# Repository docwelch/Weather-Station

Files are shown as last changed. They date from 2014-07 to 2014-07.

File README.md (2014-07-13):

Weather-Station
===============

This is a weather station created with components from Sparkfun. The Arduino firmware is a modified version of Sparkfun's Wimp Weather Station. While the Imp is an interesting device, I wanted to get the weather data back to a BeagleBone Black for further processing/evaluation. The BeagleBone Black can easily push the data to Weather Underground. 

##Equipment

To set up your station, please follow the [Sparkfun tutorial](https://learn.sparkfun.com/tutorials/weather-station-wirelessly-connected-to-wunderground). Obviously, you won't need the Imp or the Imp shield. In its place, you will need an XBee shield, an XBee breakout (with headers) and and two XBees. I am using XBee Pro modules due to the distance and other factors. You will need *three* sets of Arduino headers (one for the XBee shield and two for the weather shield) because the weather shield is so tall. So that we can turn the XBee off and on to conserve power, you will need a connection between the XBee pin 9 and digital pin 4 on the RedBoard.

I am using a BeagleBone Black Rev. C (a Rev. B board would work as well if you have one) running [Debian](http://beagleboard.org/latest-images/). You will need to have your BeagleBone Black connected to the internet (wired or wireless) if you want to push your data to Weather Underground. On the P9 header of the BeagleBone Black, connect pin 1 to ground on the XBee breakout, pin 3 to VCC on the XBee breakout, pin 21 (Serial 2 TX) to DIN on the XBee breakout, and pin 26 (Serial 1 RX) to DOUT on the XBee breakout.

To house the electronics, I 3-d printed a Stevenson Screen. I used the pins.scad file from [Thingiverse](http://www.thingiverse.com/thing:10541/#files) to create pins and sockets to make it easy to assemble/disassemble the screen. I have included the .STL files for printing and the OpenScad file for the bottom so that you may modify it for your own mounting system. The Stevenson screen is printed in white PLA. It remains to be seen how durable the PLA will be. You build the assembly with a top, a middle, a middle grid, two more middles, and a bottom. The battery and Sunny Buddy sit on top of the middle grid. The bottom has holes to mount the RedBoard and the two shields.
For now, I have the solar panel mounted in a manner similar to the Sparkfun Wimp Weather Station. I am thinking of designing a gimbal driven by two servos to track the sun. There should still be enough memory on the RedBoard for this.

##Libraries

You will need the [xbee-arduino library](https://code.google.com/p/xbee-arduino/) as well as the [pressure](https://github.com/sparkfun/MPL3115A2_Breakoutand) and [humidity](https://github.com/sparkfun/HTU21D_Breakout) sensor libraries from Sparkfun. 
For the BeagleBone Black, you will need (in addition to libraries bonescript, socketio, and serial installed by default) [xbee-api](https://www.npmjs.org/package/xbee-api) and [moment](https://www.npmjs.org/package/moment). Unless you are using the latest Bonescript from Github, you need to modify your serial.js file (found in /usr/local/lib/node_modules/bonescript) to include the following line at the end of the file: `exports.serialParsers = m.module.exists ? m.module.parsers : {};`

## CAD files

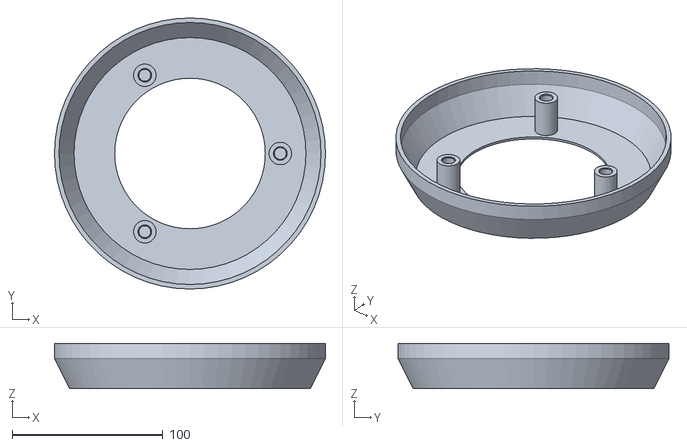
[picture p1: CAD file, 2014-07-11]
Stevenson Screen/Middle.stl
180.0 x 180.0 x 30.0

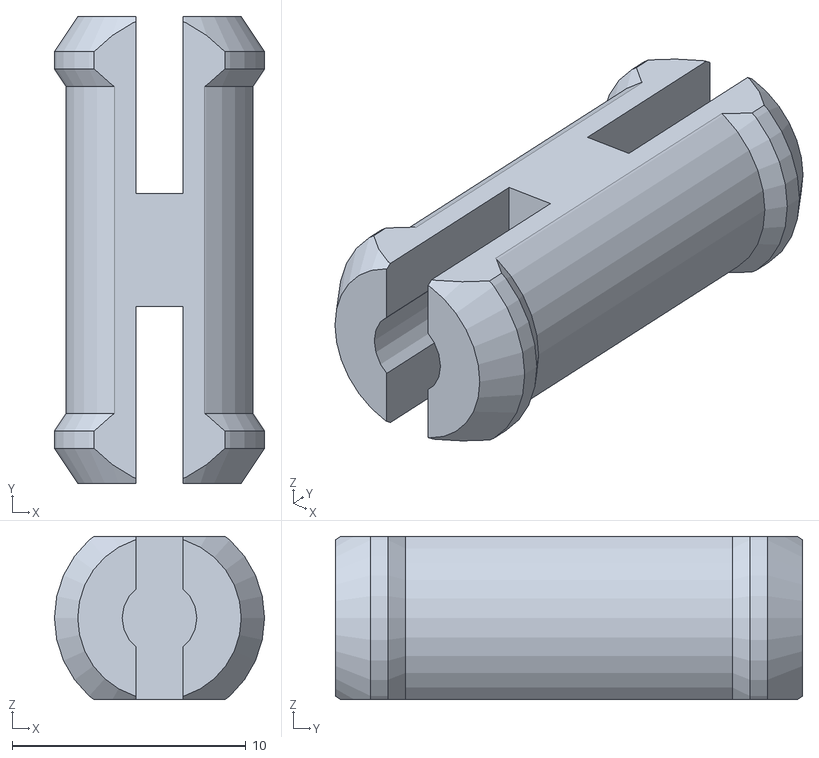
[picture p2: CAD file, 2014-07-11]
Stevenson Screen/SinglePin.stl
9.00 x 20.0 x 7.00

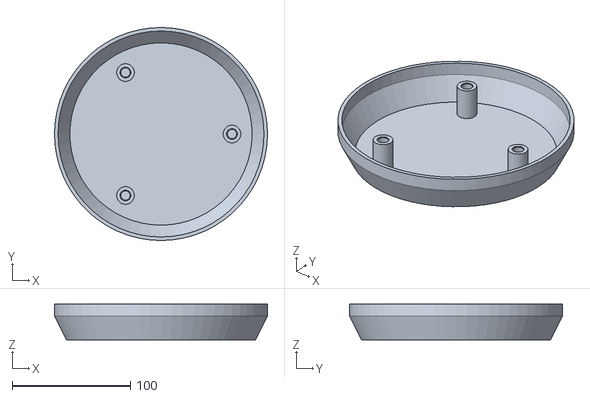
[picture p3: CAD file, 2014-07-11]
Stevenson Screen/Top.stl
180.0 x 180.0 x 30.0

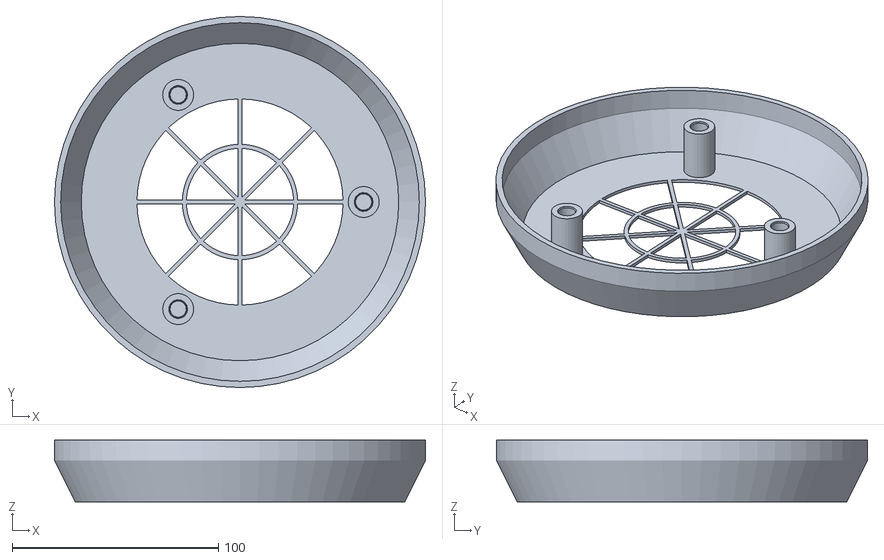
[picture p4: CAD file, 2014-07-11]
Stevenson Screen/Middle_grid.stl
180.0 x 180.0 x 30.0

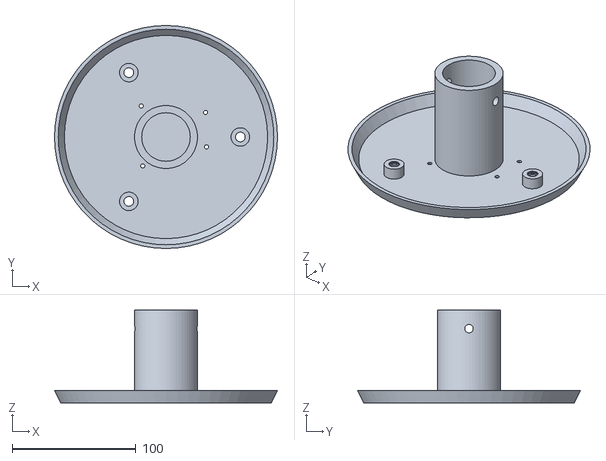
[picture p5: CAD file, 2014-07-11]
Stevenson Screen/Bottom.stl
180.0 x 180.0 x 75.0

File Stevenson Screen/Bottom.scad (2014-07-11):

include <pins.scad>;

difference(){
	union(){
		main();
		verticals();
		mount();
	}
	holes();
	rotate([180,0,0])translate([-34,-27.5,-4]){
		translate([14,2.5,0])cylinder(h=5,r=1.7,$fn=30);
		translate([66,7.62,0])cylinder(h=5,r=1.7,$fn=30);
		translate([15.25,50.8,0])cylinder(h=5,r=1.7,$fn=30);
		translate([66.7,35.50,0])cylinder(h=5,r=1.7,$fn=30);
	}
}

module mount(){
	difference(){
		cylinder(h=75, r=25.4, $fn=60);
		translate([0,0,10])cylinder(h=66, r=19.6, $fn=60);
		translate([0,0,60])rotate([0,90,0])cylinder(h=80, r=3.43, $fn=30, center=true);
	}
}

module main(){
	difference(){
		cylinder(h=10,r1=85,r2=90,$fn=60);
		translate([0,0,1.5])cylinder(h=8.6,r1=82,r2=87,$fn=60);
	}
}

module verticals(){
	translate([60,0,0])cylinder(h=10,r=7.5,$fn=30);
	rotate([0,0,120])translate([60,0,0])cylinder(h=10,r=7.5,$fn=30);
	rotate([0,0,-120])translate([60,0,0])cylinder(h=10,r=7.5,$fn=30);
}

module holes(){
	translate([60,0,0])pinhole(h=10);
	rotate([0,0,120])translate([60,0,0])pinhole(h=10);
	rotate([0,0,-120])translate([60,0,0])pinhole(h=10);
}

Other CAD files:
Stevenson Screen/pins.scad

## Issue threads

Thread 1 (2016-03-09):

No transmission data to Wunderground / Error in Arduino Function missing

golvellius, 2016-03-09:
Hi ...

First of all i would like to thank you about your supperb work .. I have been checking your code and works ok .
I have found two possible errors i can not recover ...
1) In the code of BeagleBoneBlack . The info arrives  from the arduino , it is displayed in the console of cloud9 IDE ,   but **never execute sendDataToWunderground()**; .. I see all the info comming from the arduino , but never sends data to internet ...

2) Also there is a problem in the code of the Arduino , Line ...
**baromin = myPressure.readPressureinHg(LOCAL_ALT_METERS); **
I tried to get some libraries from internet , included the ones in SPARKFUN but no luck , the function does not exist .. I have made new routine from example in SPARKFUN .. i will check ...

Maybe i make some mistake ...

Thanks a lot ...

docwelch, 2016-03-10:
For issue #1, the problem is likely a small typo in function sendDataToWunderground(). I had a lot of trouble with my system as well. Please go back and review that you have your username and password correct and no other mistakes in the function where it creates the http request. When I was setting up my station, I had to review that section several times before I finally got all the errors out of it.

For issue 2, it looks like Sparkfun has changed the library since I downloaded it. You are correct, the function no longer exists. They have made a lot of changes to the library it looks like and this will require some re-writing of the code. It should not be too difficult if you look at the example sketches [Sparkfun MPL3115A2 Pressure Sensor Library.](https://github.com/sparkfun/SparkFun_MPL3115A2_Breakout_Arduino_Library.) You can also look at [Sparkfun Wimp Weather Station Arduino Code](https://github.com/sparkfun/Wimp_Weather_Station/blob/master/Wimp_Weather_Station.ino) as it looks like Sparkfun updated this as well. Looks like you just need to set up the barometer in the void Setup() function, and then you call for pressure with just readPressure(). It returns the value in Pa so you will have to convert if you want a different unit. You will no longer need the LOCAL_ALT_METERS variable.

Glad this is useful to someone and I hope my response is helpful. Let me know if you cannot figure it out. I think I may have to take down my weather station and add the lightning sensor. I am sure I will change over to the new library and I will update the code then. However, it may be several weeks (or months) before I get to it, unfortunately. I will leave this issue open until I have time to fix the code.

golvellius, 2016-03-10:
Hi  ...
I think i have my issue  with the code .. maybe hardware xbee issue ...

What  i see is that i get data from the xbee but maybe wrong data ..

On this function ...i modified to tell me things in the console ...

xbeeAPI.on('frame_object',function(frame){
    console.log("XBEE");
    if (frame.type==C.FRAME_TYPE.RX_PACKET_16){
        console.log("XBEEIN");
        dataArray.length=0;
        weatherArray.length=0;
        var winddir=((frame.data[0]<<8)+frame.data[1]);
etc ....

I see in the console XBEE but not XBEE1 ... never execute this function ...

Can you tell me your xbee configuration .... ?

I think that this is the problem ...

golvellius, 2016-03-10:
Hi ...

Now Working .. it's a problem with the ap mode of the xbeess ... Now working OK ...

If you want i can add the code in your source to readPressure in HG ....

Thanks a lot ...

golvellius, 2016-06-07:
Hi ..

I have been using it for 2 month , but i have problems maybe with my battery charger ..
Suddenly , battery get's empty an solar panel can not charge ...

What are you using ? Solar Panel + BAttery charger + batteries ?

Thanks a lot ... Good job with this project ...
I am modifying the code to install lighting detector .... ; )

Please can you reply to me to this email golvelliuscs@hotmail.com ..

bye

docwelch, 2016-06-08:
I used a 2.5W solar cell and the Sunny Buddy MPPT charger from Sparkfun with a 5000mAh single cell LiPo battery.I never had a problem, even with several days of limited to no sunshine. I think the 5000mAh battery is probably quite a bit bigger than you would have to use, but they are cheap from HobbyKing.
Good luck with it,Steven
 Confidentiality Statement - This electronic message transmission contains information that is confidential or privileged.  The information is intended to be for the use of the individual or entity named above. If you are not the  intended recipient, be aware that any disclosure, copying, distribution or use of the contents of this information is prohibited.  If you have received this electronic transmission in error, please notify us immediately.  Thank you.

      From: golvellius <notifications@github.com>
 To: docwelch/Weather-Station <Weather-Station@noreply.github.com>
Cc: Steven Welch <docwelch@yahoo.com>; Comment <comment@noreply.github.com>
 Sent: Tuesday, June 7, 2016 5:47 AM
 Subject: Re: [docwelch/Weather-Station] No transmission data to Wunderground / Error in Arduino Function missing (#1)

Hi ..I have been using it for 2 month , but i have problems maybe with my battery charger ..
Suddenly , battery get's empty an solar panel can not charge ... What are you using ? Solar Panel + BAttery charger + batteries ?Thanks a lot ... Good job with this project ...
I am modifying the code to install lighting detector .... ; ) Please can you reply to me to this email golvelliuscs@hotmail.com ..bye —
You are receiving this because you commented.
Reply to this email directly, view it on GitHub, or mute the thread.

Closed 2016-03-11.

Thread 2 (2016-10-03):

Pressure reading error

golvellius, 2016-10-03:
Hi ...
My system :

Arduino uno R3 ( +5 volts ) + Xbee (first version) + Weather Shield ( sparkfun ) + Weather Meters ( SParkfun)+ BBB  ...
I have a problem when retrieving the pression from the arduino ...

To get a good values i need to remove this line in  the code  :

**// myPressure.setModeActive(); // Go to active mode and start measuring!**

Also i change this value (128) to (7) in this line :

 **myPressure.setOversampleRate(7); // Set Oversample to the recommended 128**

But the error is that the values i get from the sensor is too  high 255825.00 after conversion  = example 75.72 inHg ..
Sometimes i get 0 from the arduino ...

I used this formula to get the pressure from pascals to inhg :

 **payload[23] = tdailyrainin & 0xFF;**
**// Calculo la presion en hpa para enviar a wunther**

  **float pressure = baromin / 100; //pressure is now in millibars**

  **float part1 = pressure - 0.3; //Part 1 of formula**

  **const float part2 = 8.42288 / 100000.0;**
  **float part3 = pow((pressure - 0.3), 0.190284);**
  **float part4 = LOCAL_ALT_METERS / part3; // Local_Alt_Meters esta ya en coma flotante**
  **float part5 = (1.0 + (part2 * part4));**
  **float part6 = pow(part5, (1.0/0.190284));**
  **float altimeter_setting_pressure_mb = part1 * part6; //Output is now in adjusted millibars**
  **float baroin = altimeter_setting_pressure_mb * 0.02953;**

  **unsigned int tpressure = (unsigned int)(baro**in * 100);
  **payload[24] = tpressure >> 8 & 0xFF;**
  **payload[25] = tpressure & 0xFF;**

what could be the problem ...  a faulty weathershield / arduino ?

Also , sometimes i get that i have rain , but there is no raining ... maybe daily rain =0.09 , 0,10 .. etc .. if i reset the arduino rain = 0 ... after 2 hours rain =0.3 ... etc ...

Thanks so much ...

golvellius, 2016-10-19:
HI .. I think it's a problem of the sensor installed in the weathershield ...
Now i am using external sensor from bosch BMP280 and works correctly ...

Also i have added to my code an uv sensor .. i have to check if works correctly ..

Thanks a lot ... And sorry for this issue ... ;)

Closed 2016-10-19.

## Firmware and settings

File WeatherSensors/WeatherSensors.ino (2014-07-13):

/* 
 Weather Station
 By: J. Steven Welch
 July 10, 2014
 Much of this code is based on Nathan Seidle's code which is in turn based on Mike Grusin's USB Weather Board code.
 
 This code reads all the various sensors (wind speed, direction, rain gauge, humidty, pressure, light, batt_lvl)
 and sends it, via XBee, to a BeagleBone Black. The BeagleBone black then forwards that data to Weather Underground.
*/
#include <avr/wdt.h> //We need watch dog for this program
#include <Wire.h> //I2C needed for sensors
#include "MPL3115A2.h" //Pressure sensor
#include "HTU21D.h" //Humidity sensor
#include <XBee.h>

MPL3115A2 myPressure; //Create an instance of the pressure sensor
HTU21D myHumidity; //Create an instance of the humidity sensor
XBee xbee=XBee();

//Hardware pin definitions
//-=-=-=-=-=-=-=-=-=-=-=-=-=-=-=-=-=-=-=-=-=-=-=-=-=-=-=-=
// digital I/O pins
const byte WSPEED = 3;
const byte RAIN = 2;
const byte STAT1 = 7;
const byte XBEE_SLEEP_PIN = 4;

// analog I/O pins
const byte WDIR = A0;
const byte LIGHT = A1;
const byte BATT = A2;
const byte REFERENCE_3V3 = A3;
//-=-=-=-=-=-=-=-=-=-=-=-=-=-=-=-=-=-=-=-=-=-=-=-=-=-=-=-=

//Global Variables
//-=-=-=-=-=-=-=-=-=-=-=-=-=-=-=-=-=-=-=-=-=-=-=-=-=-=-=-=
//*****************************************************************
const float LOCAL_ALT_METERS=371.0; //SET FOR YOUR LOCAL ALTITUDE *
//*****************************************************************
long lastSecond; //The millis counter to see when a second rolls by
byte seconds; //When it hits 60, increase the current minute
byte seconds_2m; //Keeps track of the "wind speed/dir avg" over last 2 minutes array of data
byte minutes; //Keeps track of where we are in various arrays of data
byte minutes_10m; //Keeps track of where we are in wind gust/dir over last 10 minutes array of data

long lastWindCheck = 0;
volatile long lastWindIRQ = 0;
volatile byte windClicks = 0;
volatile long lastRainIRQ = 0;

uint8_t payload[32]; //buffer for data to send through XBee
uint8_t respData=0; //byte to hold data sent from BeagleBone to trigger events on the Arduino
//******************************************************************************************************************************
Tx16Request tx=Tx16Request(0x1000,payload,sizeof(payload)); //XBee packet to send - SET THE FIRST VALUE TO YOUR OWN XBEE VALUE *
//******************************************************************************************************************************
Rx16Response rx16 = Rx16Response();
uint8_t reportTime=20; //how often to report the weather - can be updated from BBB
uint8_t counter=0; //counter to track seconds for the above reportTime

//We need to keep track of the following variables:
//Wind speed/dir each update (no storage)
//Wind gust/dir over the day (no storage)
//Wind speed/dir, avg over 2 minutes (store 1 per second)
//Wind gust/dir over last 10 minutes (store 1 per minute)
//Rain over the past hour (store 1 per minute)
//Total rain over date (store one per day)

byte windspdavg[120]; //120 bytes to keep track of 2 minute average
int winddiravg[120]; //120 ints to keep track of 2 minute average
float windgust_10m[10]; //10 floats to keep track of 10 minute max
int windgustdirection_10m[10]; //10 ints to keep track of 10 minute max
volatile float rainHour[60]; //60 floating numbers to keep track of 60 minutes of rain

//These are all the weather values that wunderground expects:
int winddir; // [0-360 instantaneous wind direction]
float windspeedmph; // [mph instantaneous wind speed]
float windgustmph; // [mph current wind gust, using software specific time period]
int windgustdir; // [0-360 using software specific time period]
float windspdmph_avg2m; // [mph 2 minute average wind speed mph]
int winddir_avg2m; // [0-360 2 minute average wind direction]
float windgustmph_10m; // [mph past 10 minutes wind gust mph ]
int windgustdir_10m; // [0-360 past 10 minutes wind gust direction]
float humidity; // [%]
float tempf; // [temperature F]
float rainin; // [rain inches over the past hour)] -- the accumulated rainfall in the past 60 min
volatile float dailyrainin; // [rain inches so far today in local time]
float baromin;//a calculated number
float pressure;//a raw reading
float dewptf;//a calculated number

//These are not wunderground values, they are just for us
float batt_lvl = 4.0;
float light_lvl = 2.2;

// volatiles are subject to modification by IRQs
extern volatile unsigned long timer0_millis;
//-=-=-=-=-=-=-=-=-=-=-=-=-=-=-=-=-=-=-=-=-=-=-=-=-=-=-=-=

//Interrupt routines (these are called by the hardware interrupts, not by the main code)
//-=-=-=-=-=-=-=-=-=-=-=-=-=-=-=-=-=-=-=-=-=-=-=-=-=-=-=-=
void rainIRQ()
// Count rain gauge bucket tips as they occur
// Activated by the magnet and reed switch in the rain gauge, attached to input D2
{
  if (millis() - lastRainIRQ > 10)
  {
    lastRainIRQ=millis();
    dailyrainin +=0.011;
    rainHour[minutes]+=0.011;
  }
}

void wspeedIRQ()
// Activated by the magnet in the anemometer (2 ticks per rotation), attached to input D3
{
  if (millis() - lastWindIRQ > 10) // Ignore switch-bounce glitches less than 10ms (142MPH max reading) after the reed switch closes
  {
    lastWindIRQ = millis(); //Grab the current time
    windClicks++; //There is 1.492MPH for each click per second.
  }
}

void setup()
{
  wdt_reset(); //Pet the dog
  wdt_disable(); //We don't want the watchdog during init

  Serial.begin(9600);
  
  xbee.setSerial(Serial);
  pinMode(XBEE_SLEEP_PIN,OUTPUT);
  digitalWrite(XBEE_SLEEP_PIN,HIGH); //xbee is put to sleep

  pinMode(WSPEED, INPUT_PULLUP); // input from wind meters windspeed sensor
  pinMode(RAIN, INPUT_PULLUP); // input from wind meters rain gauge sensor

  pinMode(WDIR, INPUT);
  pinMode(LIGHT, INPUT);
  pinMode(BATT, INPUT);
  pinMode(REFERENCE_3V3, INPUT);
  
  pinMode(STAT1, OUTPUT);

  midnightReset(); //Reset rain totals

  //Configure the pressure sensor
  myPressure.begin(); // Get sensor online
  myPressure.setModeBarometer(); // Measure pressure in Pascals from 20 to 110 kPa
  myPressure.setOversampleRate(128); // Set Oversample to the recommended 128
  myPressure.enableEventFlags(); // Enable all three pressure and temp event flags 
  myPressure.setModeActive(); // Go to active mode and start measuring!

  //Configure the humidity sensor
  myHumidity.begin();

  seconds = 0;
  lastSecond = millis();

  // attach external interrupt pins to IRQ functions
  attachInterrupt(0, rainIRQ, FALLING);
  attachInterrupt(1, wspeedIRQ, FALLING);

  // turn on interrupts
  interrupts();

  wdt_enable(WDTO_1S); //Unleash the beast
}

void loop()
{
  wdt_reset(); //Pet the dog

  //Keep track of which minute it is
  if(millis() - lastSecond >= 1000)
  {
    lastSecond += 1000;

    //Take a speed and direction reading every second for 2 minute average
    if(++seconds_2m > 119) seconds_2m = 0;

    //Calc the wind speed and direction every second for 120 second to get 2 minute average
    float currentSpeed = get_wind_speed();
    windspeedmph=currentSpeed;
    int currentDirection = get_wind_direction();
    windspdavg[seconds_2m] = (int)currentSpeed;
    winddiravg[seconds_2m] = currentDirection;

    //Check to see if this is a gust for the minute
    if(currentSpeed > windgust_10m[minutes_10m])
    {
      windgust_10m[minutes_10m] = currentSpeed;
      windgustdirection_10m[minutes_10m] = currentDirection;
    }

    //Check to see if this is a gust for the day
    //Resets at midnight each night
    if(currentSpeed > windgustmph)
    {
      windgustmph = currentSpeed;
      windgustdir = currentDirection;
    }

    //Blink stat LED briefly to show we are alive
    digitalWrite(STAT1, HIGH);
    delay(25);
    digitalWrite(STAT1, LOW);
    
    //Is it time to report the weather?
    if (++counter>=reportTime)
    {
      counter=0;
      reportWeather();
    }
    //If we roll over 60 seconds then update the arrays for rain and windgust
    if(++seconds > 59)
    {
      seconds = 0;
      if(++minutes > 59) minutes = 0;
      if(++minutes_10m > 9) minutes_10m = 0;

      rainHour[minutes] = 0; //Zero out this minute's rainfall amount
      windgust_10m[minutes_10m] = 0; //Zero out this minute's gust
    }
  }
//******************************************
  //See if we got something from the BeagleBoneBlack
  if(respData!=0)
  {
    if(respData == 0xFE) //Indicates that it is midnight local time
    {
      midnightReset(); //Reset a bunch of variables like rain and total rain
    }
    else if(respData == 0xFF) //Force a hardware reset
    {
      delay(2500); //This will cause the system to reset because we don't pet the dog
    }else{ //We got a reportTime number
      reportTime=respData; //Can report data every 3 to 253 seconds
      //Note that Weather Underground will not take data faster than every 2.5 seconds. 
    }
    respData=0;
  }
  delay(100); //Update every 100ms. No need to go any faster.
}

//When the BBB tells us it's midnight, reset some things
//millis() gets reset to zero here as well so there are no rollover issues
void midnightReset()
{
  //reset millis
  uint8_t oldSREG=SREG;
  cli();
  timer0_millis=(long)0;
  SREG=oldSREG;
  
  dailyrainin = 0; //Reset daily amount of rain

  windgustmph = 0; //Zero out this minute's gust
  windgustdir = 0; //Zero out the gust direction
  
  minutes = 0; //Reset minute tracker
  seconds = 0;
  lastSecond = millis(); //Reset variable used to track minutes
  lastWindCheck=millis(); //Reset variable to track instantaneous wind speed
  lastRainIRQ=millis();
  lastWindIRQ=millis();
}

//Calculates each of the variables that wunderground is expecting
void calcWeather()
{
  //Calc winddir
  winddir = get_wind_direction();

  //windspeedmph already calcuated in main loop
  //windgustmph and windgustdir are calculated throughout the day

  //Calc windspdmph_avg2m
  float temp = 0;
  for(int i = 0 ; i < 120 ; i++)
    temp += windspdavg[i];
  temp /= 120.0;
  windspdmph_avg2m = temp;

  //Calc winddir_avg2m
  temp = 0; //Can't use winddir_avg2m because it's an int
  for(int i = 0 ; i < 120 ; i++)
    temp += winddiravg[i];
  temp /= 120;
  winddir_avg2m = temp;

  //Calc windgustmph_10m
  //Calc windgustdir_10m
  //Find the largest windgust in the last 10 minutes
  windgustmph_10m = 0;
  windgustdir_10m = 0;
  //Step through the 10 minutes  
  for(int i = 0; i < 10 ; i++)
  {
    if(windgust_10m[i] > windgustmph_10m)
    {
      windgustmph_10m = windgust_10m[i];
      windgustdir_10m = windgustdirection_10m[i];
    }
  }

  //Calc humidity
  humidity = myHumidity.readHumidity();

  //Calc tempf from pressure sensor
  tempf = myPressure.readTempF();

  //Total rainfall for the day is calculated within the interrupt
  //Calculate amount of rainfall for the last 60 minutes
  rainin = 0;  
  for(int i = 0 ; i < 60 ; i++)
    rainin += rainHour[i];

  //Calc pressure
  baromin = myPressure.readPressureinHg(LOCAL_ALT_METERS);

  //Calc dewptf
  float tempC=(tempf-32)*5/9.0;
  float L=log(humidity/100.0);
  float M=17.27*tempC;
  float N=237.3+tempC;
  float B=(L+(M/N))/17.27;
  dewptf=((237.3*B)/(1.0-B))*9/5.0 +32;
  
  //Calc light level
  light_lvl = get_light_level();

  //Calc battery level
  batt_lvl = get_battery_level();
}

//Returns the voltage of the light sensor based on the 3.3V rail
//This allows us to ignore what VCC might be (an Arduino plugged into USB has VCC of 4.5 to 5.2V)
float get_light_level()
{
  float operatingVoltage = averageAnalogRead(REFERENCE_3V3);

  float lightSensor = averageAnalogRead(LIGHT);
  
  operatingVoltage = 3.3 / operatingVoltage; //The reference voltage is 3.3V
  
  lightSensor *= operatingVoltage;
  
  return(lightSensor);
}

//Returns the voltage of the raw pin based on the 3.3V rail
//This allows us to ignore what VCC might be (an Arduino plugged into USB has VCC of 4.5 to 5.2V)
//Battery level is connected to the RAW pin on Arduino and is fed through two 5% resistors:
//3.9K on the high side (R1), and 1K on the low side (R2)
float get_battery_level()
{
  float operatingVoltage = averageAnalogRead(REFERENCE_3V3);

  float rawVoltage = averageAnalogRead(BATT);
  
  operatingVoltage = 3.30 / operatingVoltage; //The reference voltage is 3.3V
  
  rawVoltage *= operatingVoltage; //Convert the 0 to 1023 int to actual voltage on BATT pin
  
  rawVoltage *= 4.90; //(3.9k+1k)/1k - multiply BATT voltage by the voltage divider to get actual system voltage
  
  return(rawVoltage);
}

//Returns the instataneous wind speed
float get_wind_speed()
{
  float deltaTime = millis() - lastWindCheck; //750ms

  deltaTime /= 1000.0; //Covert to seconds

  float windSpeed = (float)windClicks / deltaTime; //3 / 0.750s = 4

  windClicks = 0; //Reset and start watching for new wind
  lastWindCheck = millis();

  windSpeed *= 1.492; //4 * 1.492 = 5.968MPH

  return(windSpeed);
}

int get_wind_direction() 
// read the wind direction sensor, return heading in degrees
{
  unsigned int adc;

  adc = averageAnalogRead(WDIR); // get the current reading from the sensor

  // The following table is ADC readings for the wind direction sensor output, sorted from low to high.
  // Each threshold is the midpoint between adjacent headings. The output is degrees for that ADC reading.
  // Note that these are not in compass degree order! See Weather Meters datasheet for more information.

  if (adc < 380) return (113);
  if (adc < 393) return (68);
  if (adc < 414) return (90);
  if (adc < 456) return (158);
  if (adc < 508) return (135);
  if (adc < 551) return (203);
  if (adc < 615) return (180);
  if (adc < 680) return (23);
  if (adc < 746) return (45);
  if (adc < 801) return (248);
  if (adc < 833) return (225);
  if (adc < 878) return (338);
  if (adc < 913) return (0);
  if (adc < 940) return (293);
  if (adc < 967) return (315);
  if (adc < 990) return (270);
  return (-1); // error, disconnected?
}


//Reports the weather string to the BBB
void reportWeather()
{
  calcWeather(); //Go calc all the various sensors
  //load all data into the payload buffer for transfer to the BBB
  payload[0]=winddir>>8 & 0xFF;
  payload[1]=winddir & 0xFF;
  payload[6]=windgustdir>>8 & 0xFF;
  payload[7]=windgustdir & 0xFF;
  payload[10]=winddir_avg2m>>8 & 0xFF;
  payload[11]=winddir_avg2m & 0xFF;
  payload[14]=windgustdir_10m>>8 & 0xFF;
  payload[15]=windgustdir_10m & 0xFF;
  //convert floats to unsigned ints as they will not be bigger than 16 bits (even when multiplied by 100)
  unsigned int twindspeedmph=(unsigned int)(windspeedmph*10);
  payload[2]=twindspeedmph>>8 & 0xFF;
  payload[3]=twindspeedmph & 0xFF;
  unsigned int twindgustmph=(unsigned int)(windgustmph*10);
  payload[4]=twindgustmph>>8 & 0xFF;
  payload[5]=twindgustmph & 0xFF;
  unsigned int twindspdmph_avg2m=(unsigned int)(windspdmph_avg2m*10);
  payload[8]=twindspdmph_avg2m>>8 & 0xFF;
  payload[9]=twindspdmph_avg2m & 0xFF;
  unsigned int twindgustmph_10m=(unsigned int)(windgustmph_10m*10);
  payload[12]=twindgustmph_10m>>8 & 0xFF;
  payload[13]=twindgustmph_10m & 0xFF;
  unsigned int thumidity=(unsigned int)(humidity*10);
  payload[16]=thumidity>>8 & 0xFF;
  payload[17]=thumidity & 0xFF;
  unsigned int ttempf=(unsigned int)(tempf*10);
  payload[18]=ttempf>>8 & 0xFF;
  payload[19]=ttempf & 0xFF;
  unsigned int trainin=(unsigned int)(rainin*100);
  payload[20]=trainin>>8 & 0xFF;
  payload[21]=trainin & 0xFF;
  unsigned int tdailyrainin=(unsigned int)(dailyrainin*100);
  payload[22]=tdailyrainin>>8 & 0xFF;
  payload[23]=tdailyrainin & 0xFF;
  unsigned int tpressure=(unsigned int)(baromin*100);
  payload[24]=tpressure>>8 & 0xFF;
  payload[25]=tpressure & 0xFF;
  unsigned int tdewptf=(unsigned int)(dewptf*10);
  payload[26]=tdewptf>>8 & 0xFF;
  payload[27]=tdewptf & 0xFF;
  unsigned int tbatt_lvl=(unsigned int)(batt_lvl*100);
  payload[28]=tbatt_lvl>>8 & 0xFF;
  payload[29]=tbatt_lvl & 0xFF;
  unsigned int tlight_lvl=(unsigned int)(light_lvl*100);
  payload[30]=tlight_lvl>>8 & 0xFF;
  payload[31]=tlight_lvl & 0xFF;
  digitalWrite(XBEE_SLEEP_PIN,LOW); //wake up the xbee
  delay(50); //give it time to wake up
  xbee.send(tx); //send the data
  wdt_reset(); //Pet the dog
  long newTime=millis();
  while (millis()-newTime <=500) //we give the BBB 500 mS to respond
  {
    xbee.readPacket();
    if (xbee.getResponse().isAvailable())
    {
      if (xbee.getResponse().getApiId()==RX_16_RESPONSE)
      {
        xbee.getResponse().getRx16Response(rx16);
        respData=rx16.getData(0);
      }
    }
  }
  wdt_reset(); //Pet the dog again
  digitalWrite(XBEE_SLEEP_PIN,HIGH); //put it back to sleep
/*
  Serial.println();
  Serial.print("$,winddir=");
  Serial.print(winddir);
  Serial.print(",windspeedmph=");
  Serial.print(windspeedmph, 1);
  Serial.print(",windgustmph=");
  Serial.print(windgustmph, 1);
  Serial.print(",windgustdir=");
  Serial.print(windgustdir);
  Serial.print(",windspdmph_avg2m=");
  Serial.print(windspdmph_avg2m, 1);
  Serial.print(",winddir_avg2m=");
  Serial.print(winddir_avg2m);
  Serial.print(",windgustmph_10m=");
  Serial.print(windgustmph_10m, 1);
  Serial.print(",windgustdir_10m=");
  Serial.print(windgustdir_10m);
  Serial.print(",humidity=");
  Serial.print(humidity, 1);
  Serial.print(",tempf=");
  Serial.print(tempf, 1);
  Serial.print(",rainin=");
  Serial.print(rainin, 2);
  Serial.print(",dailyrainin=");
  Serial.print(dailyrainin, 2);
  Serial.print(",pressure=");
  Serial.print(baromin, 2);
  Serial.print(",dewpoint=");
  Serial.print(dewptf,1);
  Serial.print(",batt_lvl=");
  Serial.print(batt_lvl, 2);
  Serial.print(",light_lvl=");
  Serial.print(light_lvl, 2);
  Serial.print(",");
  Serial.println("#");
  Serial.println();
  */
}

//Takes an average of readings on a given pin
//Returns the average
int averageAnalogRead(int pinToRead)
{
  byte numberOfReadings = 8;
  unsigned int runningValue = 0; 

  for(int x = 0 ; x < numberOfReadings ; x++)
    runningValue += analogRead(pinToRead);
  runningValue /= numberOfReadings;

  return(runningValue);  
}

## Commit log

2014-07-11 Add Stevenson Screen files
    [Bottom.scad, Bottom.stl, Middle.stl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]
2014-07-13 Initial commit of Arduino code
2014-07-14 Bug fixes and LED changes
